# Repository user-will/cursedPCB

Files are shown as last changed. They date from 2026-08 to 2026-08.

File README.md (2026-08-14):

# Cursed PCB

Cursed PCB is a programmable light board with an ATtiny412 microcontroller, four individually addressable RGB LEDs, onboard USB-C power, and an onboard CH340 SerialUPDI programmer. Plug it into a computer, install the ATtiny board support in Arduino IDE, and upload your own light patterns.

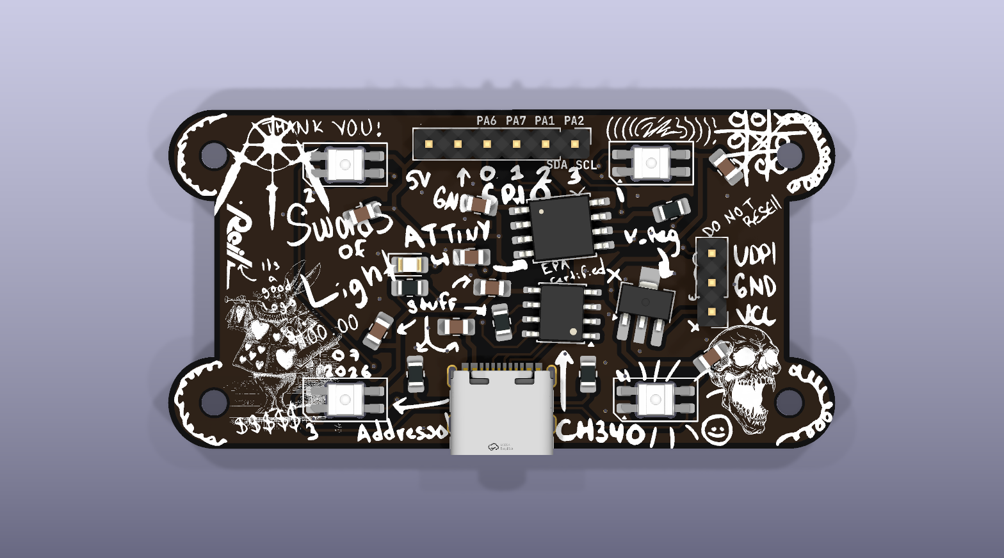
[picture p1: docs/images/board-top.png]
Top view of the Cursed PCB


> **Quick links:** [LED example](examples/LED_example/LED_example.ino) · [printable quick-start guide](docs/cursed-pcb-quick-start.pdf) · [nine-card Letter sheet](docs/cursed-pcb-card-sheet-letter-3x3.pdf) · [single 70 × 90 mm card](docs/cursed-pcb-setup-card-70x90mm.pdf) · [megaTinyCore documentation](https://github.com/SpenceKonde/megaTinyCore)

## Repository contents

- [`examples/LED_example/LED_example.ino`](examples/LED_example/LED_example.ino) — ready-to-upload LED animations and optional button support
- [`docs/cursed-pcb-quick-start.pdf`](docs/cursed-pcb-quick-start.pdf) — printable two-page quick-start guide
- [`docs/cursed-pcb-card-sheet-letter-3x3.pdf`](docs/cursed-pcb-card-sheet-letter-3x3.pdf) — nine 70 × 90 mm cards arranged 3 × 3 on US Letter paper
- [`docs/cursed-pcb-setup-card-70x90mm.pdf`](docs/cursed-pcb-setup-card-70x90mm.pdf) — one 70 × 90 mm setup card
- [`attiny412_addressable.kicad_sch`](attiny412_addressable.kicad_sch) — KiCad schematic
- [`attiny412_addressable.kicad_pcb`](attiny412_addressable.kicad_pcb) — KiCad PCB layout
- [`attiny412_addressable.kicad_pro`](attiny412_addressable.kicad_pro) — KiCad project settings

## Printing the setup cards

Use the [nine-card Letter sheet](docs/cursed-pcb-card-sheet-letter-3x3.pdf) to print nine cards on one single-sided sheet of US Letter paper or cardstock. Each finished card is 70 × 90 mm.

In the print dialog, select **Letter**, **Portrait**, **Actual size** or **100% scale**, and one-sided printing. Do not select “Fit to page.” Use the small corner marks to align your cuts.

## What you need

- The Cursed PCB
- A USB-C **data** cable (some charging-only cables cannot upload code)
- [Arduino IDE](https://www.arduino.cc/en/software)
- The `LED_example` sketch in this repository

No separate LED library download is required. The `tinyNeoPixel_Static` library used by the example is included with megaTinyCore.

## 1. Install ATtiny412 support

The ATtiny412 is not included in Arduino IDE by default. Install the **megaTinyCore** board package:

1. Open Arduino IDE.
2. Open **File → Preferences**. On macOS, open **Arduino IDE → Settings**.
3. Add this URL to **Additional Boards Manager URLs**:

   ```text
   http://drazzy.com/package_drazzy.com_index.json
   ```

   If another URL is already present, use the button beside the field and add this URL on a new line.

4. Open **Tools → Board → Boards Manager**.
5. Search for `megaTinyCore`.
6. Install the newest version of **megaTinyCore by Spence Konde**.

The package includes the compiler, upload utility, and `tinyNeoPixel` libraries needed by this board.

## 2. Connect and configure the board

Connect the board directly to the computer with a USB-C data cable. The power LED should turn on and a new serial port should appear in Arduino IDE.

Select these settings under **Tools**:

| Setting | Selection |
| --- | --- |
| Board | **megaTinyCore → ATtiny412/402/212/202** |
| Clock | **20 MHz internal** |
| BOD Voltage Level | **4.2V (20 MHz or less)** |
| millis()/micros() Timer | **Enabled (default timer)** |
| Programmer | **SerialUPDI - 230400 baud** |

Choose the board entry **without** “w/Optiboot.” This board programs the ATtiny412 directly over UPDI and does not need a bootloader.

The onboard CH340 connection is dedicated to UPDI programming. It is not connected to the ATtiny412's normal UART pins, so Arduino Serial Monitor will not display `Serial.print()` output through this USB-C connection. PA6/TX and PA7/RX remain available on the six-pin header for an external serial adapter.

## 3. Open and upload the example

1. Download or clone this repository.
2. Open [`examples/LED_example/LED_example.ino`](examples/LED_example/LED_example.ino) in Arduino IDE.
3. Compile with **Sketch → Verify/Compile**.
4. Upload with **Sketch → Upload Using Programmer**. The regular Upload button is not used for this UPDI setup.

After the upload finishes, the four LEDs run through red, green, blue, white, a rainbow sweep, and a moving white chase.

### Optional mode button

The example supports an optional normally-open pushbutton connected between exposed pins **0 (PA6)** and **2 (PA1)**. No external resistor is needed for this example: the sketch drives PA6 low and enables PA1's internal pull-up. Each press advances to the next animation.

If no button is connected, the example still works. It automatically shows the four solid colors and then continues with the rainbow sweep.

## Programming the lights

The four onboard LEDs are SK6812MINI-E addressable RGB LEDs connected as one chain. The first LED's data input is connected to **PA3**, which megaTinyCore calls Arduino pin **4**.

The important setup from the example is:

```cpp
#include <tinyNeoPixel_Static.h>

constexpr uint8_t LED_PIN = PIN_PA3;  // Arduino pin 4
constexpr uint8_t NUM_LEDS = 4;

byte pixelData[NUM_LEDS * 3];
tinyNeoPixel leds(NUM_LEDS, LED_PIN, NEO_GRB, pixelData);

void setup() {
  pinMode(LED_PIN, OUTPUT);
  leds.setBrightness(20);              // 0 to 255
  leds.setPixelColor(0, 255, 0, 0);   // first LED: red
  leds.show();
}
```

`tinyNeoPixel_Static` keeps the LED buffer in a fixed array, which is helpful on the ATtiny412's limited memory. Set colors with `setPixelColor()`, then call `show()` to send the updated buffer to the LEDs. The LEDs use `NEO_GRB` byte order.

Keep the brightness modest while experimenting. Four LEDs at full white use much more current and can be uncomfortably bright.

## Pinout

With the component side facing up and the USB-C connector at the bottom, the six-pin header reads left to right:

| Header label | Arduino pin | ATtiny412 pin | Common functions |
| --- | ---: | --- | --- |
| 5V | — | VDD | Regulated 5 V rail/output — **not an external power input** |
| GND | — | GND | Ground |
| 0 | 0 | PA6 | Digital I/O, DAC, UART TX |
| 1 | 1 | PA7 | Digital I/O, UART RX |
| 2 | 2 | PA1 | Digital I/O, I²C SDA |
| 3 | 3 | PA2 | Digital I/O, I²C SCL |

Arduino pin **4 / PA3** controls the onboard LEDs and is not on the six-pin header. **PA0 / UPDI** is reserved for programming.

The separate three-pin header is labeled **UPDI, GND, VCC** from top to bottom when the USB-C connector is at the bottom. For standalone external power, connect the supply's positive lead to **VCC** and its negative lead to **GND**. VCC feeds the onboard voltage regulator. **UPDI** is for advanced external programming; none of these pins are needed for normal USB-C programming.

## Power and handling

- For normal use, power and program the board through USB-C.
- For standalone external power, connect the supply to **VCC** and **GND** on the side three-pin header. **Do not power the board through the 5V pin.**
- VCC passes through an onboard **L78L05 linear regulator**. It produces a fixed 5 V rail and is rated for a maximum of **100 mA total output current**. The board itself and all four LEDs share that limit.
- The regulator needs approximately **7 V or more at VCC** to maintain a regulated 5 V output. Keep VCC at or below the **recommended 20 V maximum**. The regulator IC's 30 V rating is an absolute maximum, not a recommended operating voltage. Higher input voltage creates more heat and reduces the practical current available.
- Regulator heat is approximately `(VCC input − 5 V) × current`. Keep external supply voltage and LED brightness as low as practical. Four LEDs at high or full-white brightness can exceed the regulator's 100 mA rating.
- Never connect an external supply to VCC while USB-C is connected. The two power sources are not isolated.
- The exposed **5V** header pin is the regulator's output/board rail. It may be used only as a limited 5 V output when the board is properly powered; never feed an external supply into it.
- The board has exposed electronics. Prevent metal objects, conductive surfaces, and loose wires from shorting it.
- Disconnect power before changing wiring. Observe polarity when using external power.
- The LEDs can be very bright. Avoid staring directly at them at high brightness.

## Troubleshooting

### No serial port appears

- Try a known USB-C data cable and another USB port.
- Disconnect and reconnect the board while watching **Tools → Port**.
- If the computer does not recognize the onboard CH340 USB serial device, install the CH340 driver for your operating system.

### Upload fails or reports “UPDI initialization failed”

- Confirm **ATtiny412/402/212/202** (without Optiboot), **BOD Voltage Level → 4.2V**, and **SerialUPDI - 230400 baud** are selected.
- Use **Sketch → Upload Using Programmer**, not the regular Upload command.
- Close any serial monitor or other application using the board's port.
- Try **SerialUPDI - SLOW: 57600 baud** under **Tools → Programmer**.
- Unplug the board, reconnect it, reselect the port, and try again.

### The sketch uploads but the LEDs stay dark

- Confirm the sketch uses four pixels, `NEO_GRB`, and LED pin `PIN_PA3` or Arduino pin `4`.
- Make sure the LED data pin is configured as `OUTPUT` when using `tinyNeoPixel_Static`.
- Increase `setBrightness(20)` slightly while testing, but do not start at full brightness.

### The sketch is too large

The ATtiny412 has 4 KB of program flash and 256 bytes of SRAM. Prefer `tinyNeoPixel_Static`, avoid large strings and unnecessary libraries, and keep the pixel buffer at `4 × 3 = 12` bytes.

## Hardware summary

- ATtiny412, 4 KB flash / 256 bytes SRAM
- Four SK6812MINI-E addressable RGB LEDs
- USB-C connector with onboard CH340 SerialUPDI programming
- Side VCC external-power input through an L78L05 regulator: recommended 20 V maximum input, fixed 5 V output, 100 mA maximum total output
- Four exposed GPIO pins, including I²C SDA/SCL
- Approximately 58 mm × 29.5 mm
- Four 2.2 mm mounting holes

For deeper ATtiny and library information, see the official [megaTinyCore installation guide](https://github.com/SpenceKonde/megaTinyCore/blob/master/Installation.md), [megaTinyCore reference](https://github.com/SpenceKonde/megaTinyCore), and [tinyNeoPixel reference](https://github.com/SpenceKonde/megaTinyCore/blob/master/megaavr/extras/tinyNeoPixel.md).

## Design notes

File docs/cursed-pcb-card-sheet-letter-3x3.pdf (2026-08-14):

CURSED PCB | ATTINY412 / SETUP

# Set up Arduino

before uploading.

Use a USB-C data cable.

## 01 Install megaTinyCore

Arduino IDE → Preferences → Additional Boards Manager URLs:

http://drazzy.com/
package_drazzy.com_index.json
Boards Manager: install megaTinyCore by Spence Konde.
LED library included.

## 02 Choose these settings

BOARD | ATtiny412/402/212/202 without Optiboot
CLOCK | 20 MHz internal
BOD VOLTAGE | 4.2V (20 MHz or less)
PROGRAMMER | SerialUPDI – 230400 baud

## 03 Upload the example

Open LED_example.ino. Choose Sketch → Upload Using Programmer.

Power the board using the side VCC pin with up to 20V. Supplying raw voltage to the 5V pin may cause damage.

| FULL GUIDE + EXAMPLE CODE

### github.com/user-will/ cursedPCB

# STOP

CURSED PCB | ATTINY412 / SETUP

# Set up Arduino

before uploading.

Use a USB-C data cable.

## 01 Install megaTinyCore

Arduino IDE → Preferences → Additional Boards Manager URLs:

http://drazzy.com/
package_drazzy.com_index.json
Boards Manager: install megaTinyCore by Spence Konde.
LED library included.

## 02 Choose these settings

BOARD | ATtiny412/402/212/202 without Optiboot
CLOCK | 20 MHz internal
BOD VOLTAGE | 4.2V (20 MHz or less)
PROGRAMMER | SerialUPDI – 230400 baud

## 03 Upload the example

Open LED_example.ino. Choose Sketch → Upload Using Programmer.

Power the board using the side VCC pin with up to 20V. Supplying raw voltage to the 5V pin may cause damage.

| FULL GUIDE + EXAMPLE CODE

### github.com/user-will/ cursedPCB

# STOP

CURSED PCB | ATTINY412 / SETUP

# Set up Arduino

before uploading.

Use a USB-C data cable.

## 01 Install megaTinyCore

Arduino IDE → Preferences → Additional Boards Manager URLs:

http://drazzy.com/
package_drazzy.com_index.json
Boards Manager: install megaTinyCore by Spence Konde.
LED library included.

## 02 Choose these settings

BOARD | ATtiny412/402/212/202 without Optiboot
CLOCK | 20 MHz internal
BOD VOLTAGE | 4.2V (20 MHz or less)
PROGRAMMER | SerialUPDI – 230400 baud

## 03 Upload the example

Open LED_example.ino. Choose Sketch → Upload Using Programmer.

Power the board using the side VCC pin with up to 20V. Supplying raw voltage to the 5V pin may cause damage.

| FULL GUIDE + EXAMPLE CODE

### github.com/user-will/ cursedPCB

# STOP

CURSED PCB | ATTINY412 / SETUP

# Set up Arduino

before uploading.

Use a USB-C data cable.

## 01 Install megaTinyCore

Arduino IDE → Preferences → Additional Boards Manager URLs: http://drazzy.com/
package_drazzy.com_index.json
Boards Manager: install megaTinyCore by Spence Konde.
LED library included.

## 02 Choose these settings

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

## 03 Upload the example

Open LED_example.ino. Choose Sketch → Upload Using Programmer.

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

| FULL GUIDE + EXAMPLE CODE

### github.com/user-will/ cursedPCB

# STOP

CURSED PCB | ATTINY412 / SETUP

# Set up Arduino

before uploading.

Use a USB-C data cable.

## 01 Install megaTinyCore

Arduino IDE → Preferences → Additional Boards Manager URLs: http://drazzy.com/
package_drazzy.com_index.json
Boards Manager: install megaTinyCore by Spence Konde.
LED library included.

## 02 Choose these settings

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

## 03 Upload the example

Open LED_example.ino. Choose Sketch → Upload Using Programmer.

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

| FULL GUIDE + EXAMPLE CODE

### github.com/user-will/ cursedPCB

# STOP

CURSED PCB | ATTINY412 / SETUP

# Set up Arduino

before uploading.

Use a USB-C data cable.

## 01 Install megaTinyCore

Arduino IDE → Preferences → Additional Boards Manager URLs: http://drazzy.com/
package_drazzy.com_index.json
Boards Manager: install megaTinyCore by Spence Konde.
LED library included.

## 02 Choose these settings

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

## 03 Upload the example

Open LED_example.ino. Choose Sketch → Upload Using Programmer.

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

| FULL GUIDE + EXAMPLE CODE

### github.com/user-will/ cursedPCB

# STOP

CURSED PCB | ATTINY412 / SETUP

# Set up Arduino

before uploading.

Use a USB-C data cable.

## 01 Install megaTinyCore

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

## 02 Choose these settings

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

## 03 Upload the example

Open LED_example.ino. Choose Sketch → Upload Using Programmer.

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

| FULL GUIDE + EXAMPLE CODE

### github.com/user-will/ cursedPCB

# STOP

CURSED PCB | ATTINY412 / SETUP

# Set up Arduino

before uploading.

Use a USB-C data cable.

## 01 Install megaTinyCore

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

## 02 Choose these settings

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

## 03 Upload the example

Open LED_example.ino. Choose Sketch → Upload Using Programmer.

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

| FULL GUIDE + EXAMPLE CODE

### github.com/user-will/ cursedPCB

# STOP

CURSED PCB | ATTINY412 / SETUP

# Set up Arduino

before uploading.

Use a USB-C data cable.

## 01 Install megaTinyCore

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

## 02 Choose these settings

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

## 03 Upload the example

Open LED_example.ino. Choose Sketch → Upload Using Programmer.

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

| FULL GUIDE + EXAMPLE CODE

### github.com/user-will/ cursedPCB

# STOP

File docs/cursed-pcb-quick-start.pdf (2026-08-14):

PROGRAMMABLE ATTINY412 LIGHT BOARD

# Cursed PCB

Four addressable RGB LEDs, onboard USB-C power, and built-in SerialUPDI programming. This card gets the example running; the full guide and code live on GitHub.

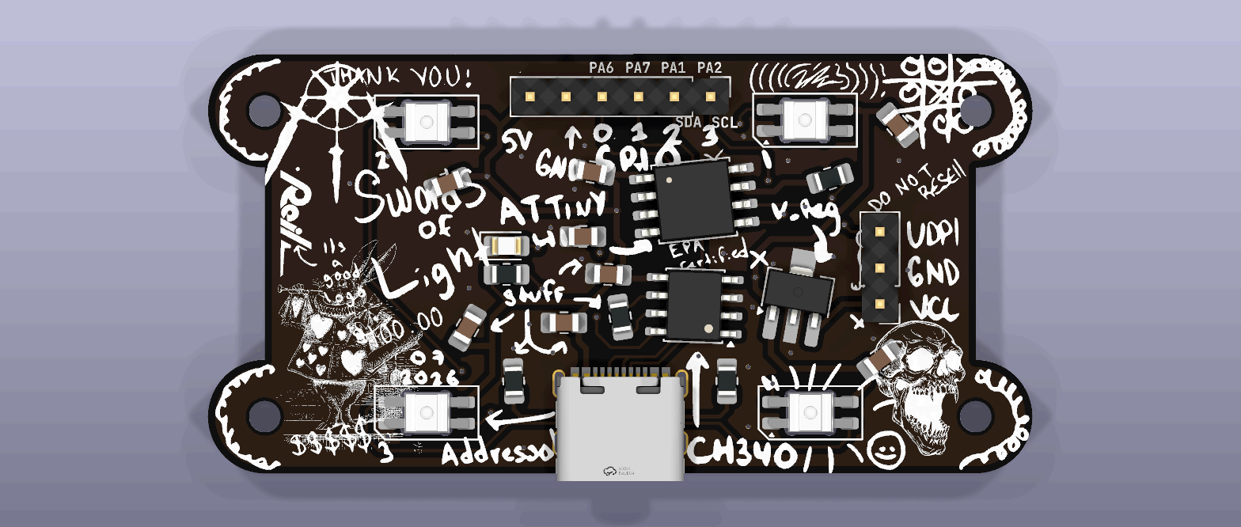
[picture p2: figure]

## Before you start

Use a USB-C data cable, not a charging-only cable.
Install Arduino IDE from arduino.cc/en/software.
No separate LED library is needed; megaTinyCore includes it.
For external power, use side-header VCC + GND—never the 5V pin. Recommended maximum: 20 V.

## Install the ATtiny board package

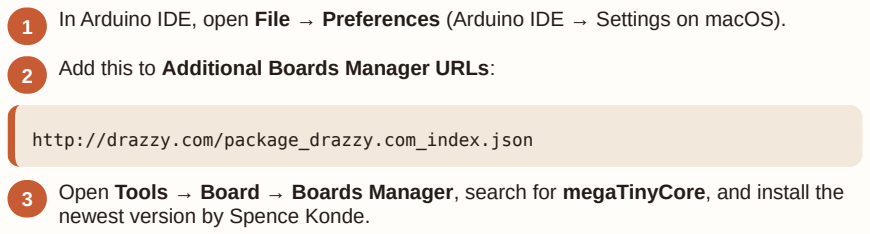
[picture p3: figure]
http://drazzy.com/package_drazzy.com_index.json; newest version by Spence Konde.

In Arduino IDE, open File → Preferences (Arduino IDE → Settings on macOS).

### 2 Add this to Additional Boards Manager URLs:

### 3 Open Tools → Board → Boards Manager, search for megaTinyCore, and install the

## Connect and choose these settings

Plug the board into the computer. The power LED should turn on and a new serial port should appear.

Tools menu | Choose
Board | ATtiny412/402/212/202 (without Optiboot)
Clock | 20 MHz internal
BOD Voltage Level | 4.2V (20 MHz or less)
Programmer | SerialUPDI - 230400 baud
Cursed PCB · Quick Start | 1 / 2

UPLOAD · PINS · TROUBLESHOOTING

# Make some light

## Get and upload the example

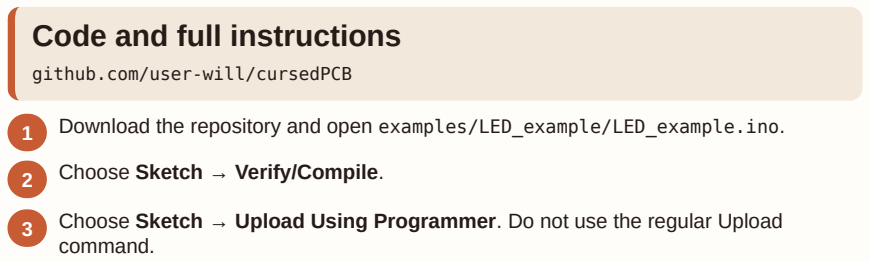
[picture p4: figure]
Code and full instructions; github.com/user-will/cursedPCB; 2 Choose Sketch → Verify/Compile.; command.

1 Download the repository and open examples/LED_example/LED_example.ino.

### 3 Choose Sketch → Upload Using Programmer. Do not use the regular Upload

The LEDs show red, green, blue, white, a rainbow sweep, and a moving white chase.

## Optional mode button

Connect a normally-open pushbutton between header pins 0 (PA6) and 2 (PA1). No external resistor is needed with the example sketch. Each press advances the animation. The LEDs still work without the button.

## Six-pin header

Component side up, USB-C at the bottom; read left to right:
Label | ATtiny | Use
5V | VDD | Regulated 5 V output; not a power input
GND | GND | Ground
0 | PA6 | Digital, DAC, TX
1 | PA7 | Digital, RX
2 | PA1 | Digital, I²C SDA
3 | PA2 | Digital, I²C SCL

The LEDs use PA3 / Arduino pin 4. PA0 is reserved for UPDI programming. The side three-pin header is UPDI, GND, VCC from top to bottom; VCC is the external-power input. The onboard USB connection programs UPDI; it is not a Serial Monitor connection.

## Troubleshooting

No port: try a known data cable or install a CH340 driver.
Upload error: recheck board, BOD voltage, and programmer; close Serial Monitor.
Still failing: select SerialUPDI - SLOW: 57600 baud.
Dark LEDs: use PIN_PA3, four pixels, and NEO_GRB.

## Power safely

| | Power the board using the side VCC pin with up to 20V. Supplying raw voltage to the 5V pin may cause damage.
Board size: about 58 × 29.5 mm | 2 / 2

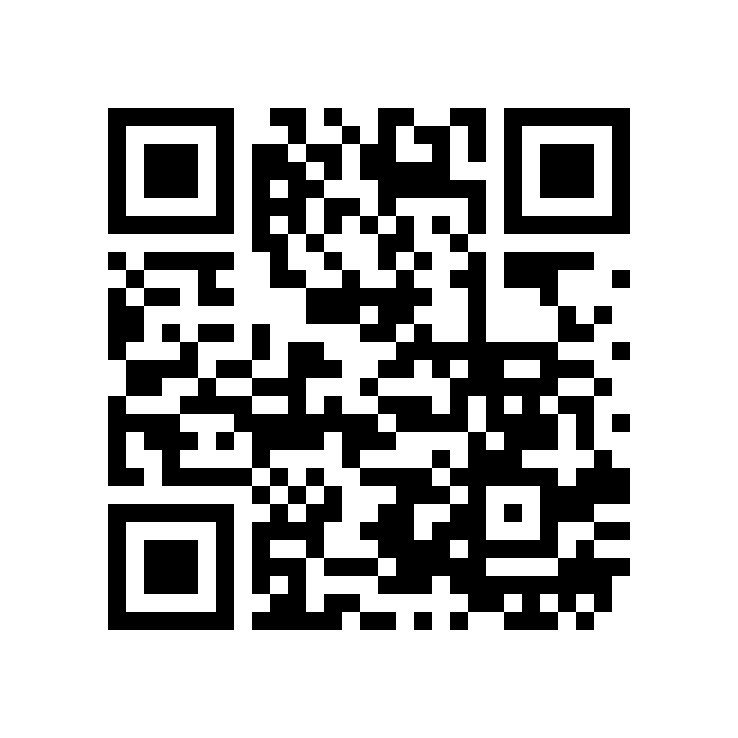
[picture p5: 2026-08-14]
docs/images/cursed-pcb-github-qr.png

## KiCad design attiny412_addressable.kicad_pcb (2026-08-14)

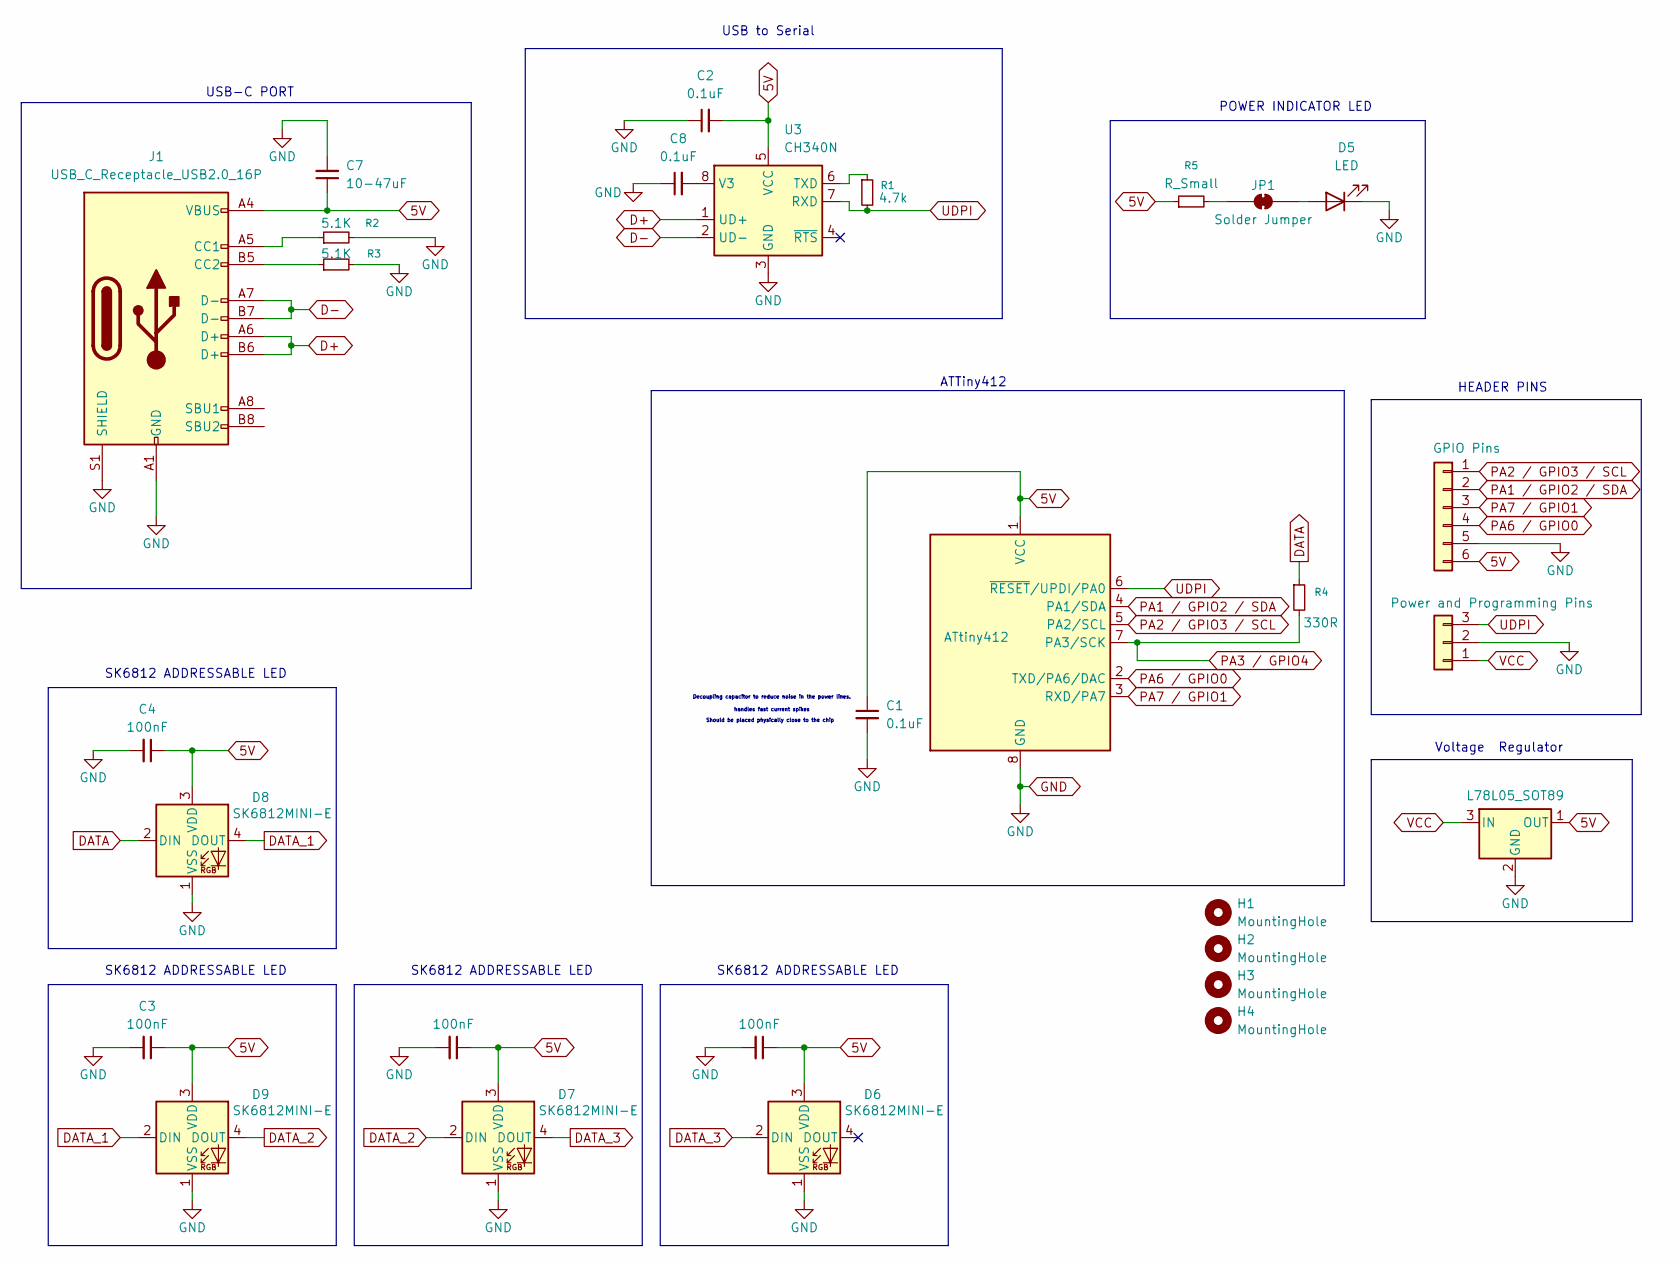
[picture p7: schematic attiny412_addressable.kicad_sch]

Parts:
C1: 0.1uF_0603_16V; C_0805_2012Metric_Pad1.18x1.45mm_HandSolder; Part Number 0603YC104KAT2A; JLCPCB ID C14663
C2, C8: 0.1uF; C_0805_2012Metric_Pad1.18x1.45mm_HandSolder
C3, C4, C5, C6: 100nF; C_0805_2012Metric_Pad1.18x1.45mm_HandSolder
C7: 10-47uF; C_0805_2012Metric_Pad1.18x1.45mm_HandSolder
D5: LED; LED_0805_2012Metric_Pad1.15x1.40mm_HandSolder
D6, D7, D8, D9: SK6812MINI-E; LED_SK6812MINI-E_3.2x2.8mm_P1.5mm_ReverseMount
H1, H2, H3, H4: MountingHole; MountingHole_2.2mm_M2
J1: USB_C_Receptacle_USB2.0_16P; USB_C_Receptacle_Palconn_UTC16-G
J2: GPIO Pins; PinHeader_1x06_P2.54mm_Vertical
J3: Power and Programming Pins; PinHeader_1x03_P2.54mm_Vertical
JP1: Solder Jumper; SolderJumper-2_P1.3mm_Bridged_RoundedPad1.0x1.5mm
R1: 4.7k; R_0805_2012Metric_Pad1.20x1.40mm_HandSolder
R2, R3: 5.1K; R_0805_2012Metric_Pad1.20x1.40mm_HandSolder
R4: 330R; R_0805_2012Metric_Pad1.20x1.40mm_HandSolder
R5: R_Small; R_0805_2012Metric_Pad1.20x1.40mm_HandSolder
U1: ATtiny412; SOIC-8_5.3x5.3mm_P1.27mm
U2: L78L05_SOT89; SOT-89-3_Handsoldering
U3: CH340N; JEITA_SOIC-8_3.9x4.9mm_P1.27mm

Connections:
5V: C1.1, C2.2, C3.1, C4.1, C5.1, C6.1, C7.1, D6.3 (VDD), D7.3 (VDD), D8.3 (VDD), D9.3 (VDD), J1.A4 (VBUS), J1.A9 (VBUS), J1.B4 (VBUS), J1.B9 (VBUS), J2.6, R5.1, U1.1 (VCC), U2.1 (OUT), U3.5 (VCC)
D+: J1.A6 (D+), J1.B6 (D+), U3.1 (UD+)
D-: J1.A7 (D-), J1.B7 (D-), U3.2 (UD-)
DATA: D8.2 (DIN), R4.1
DATA_1: D8.4 (DOUT), D9.2 (DIN)
DATA_2: D7.2 (DIN), D9.4 (DOUT)
DATA_3: D6.2 (DIN), D7.4 (DOUT)
GND: C1.2, C2.1, C3.2, C4.2, C5.2, C6.2, C7.2, C8.1, D5.1 (K), D6.1 (VSS), D7.1 (VSS), D8.1 (VSS), D9.1 (VSS), J1.A1 (GND), J1.A12 (GND), J1.B1 (GND), J1.B12 (GND), J1.S1 (SHIELD), J2.5, J3.2, R2.2, R3.2, U1.8 (GND), U2.2 (GND), U3.3 (GND)
unnamed: D5.2 (A), JP1.2 (B)
unnamed: J1.A5 (CC1), R2.1
unnamed: J1.B5 (CC2), R3.1
unnamed: JP1.1 (A), R5.2
unnamed: R1.1, U3.6 (TXD)
unnamed: C8.2, U3.8 (V3)
PA1 / GPIO2 / SDA: J2.2, U1.4 (PA1/SDA)
PA2 / GPIO3 / SCL: J2.1, U1.5 (PA2/SCL)
PA3 / GPIO4: R4.2, U1.7 (PA3/SCK)
PA6 / GPIO0: J2.4, U1.2 (TXD/PA6/DAC)
PA7 / GPIO1: J2.3, U1.3 (RXD/PA7)
UDPI: J3.3, R1.2, U1.6 (~RESET/UPDI/PA0), U3.7 (RXD)
VCC: J3.1, U2.3 (IN)

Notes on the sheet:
handles fast current spikes
SK6812 ADDRESSABLE LED
HEADER PINS
Should be placed physically close to the chip
USB to Serial
ATTiny412
POWER INDICATOR LED
USB-C PORT
Voltage Regulator
Decoupling capacitor to reduce noise in the power lines.

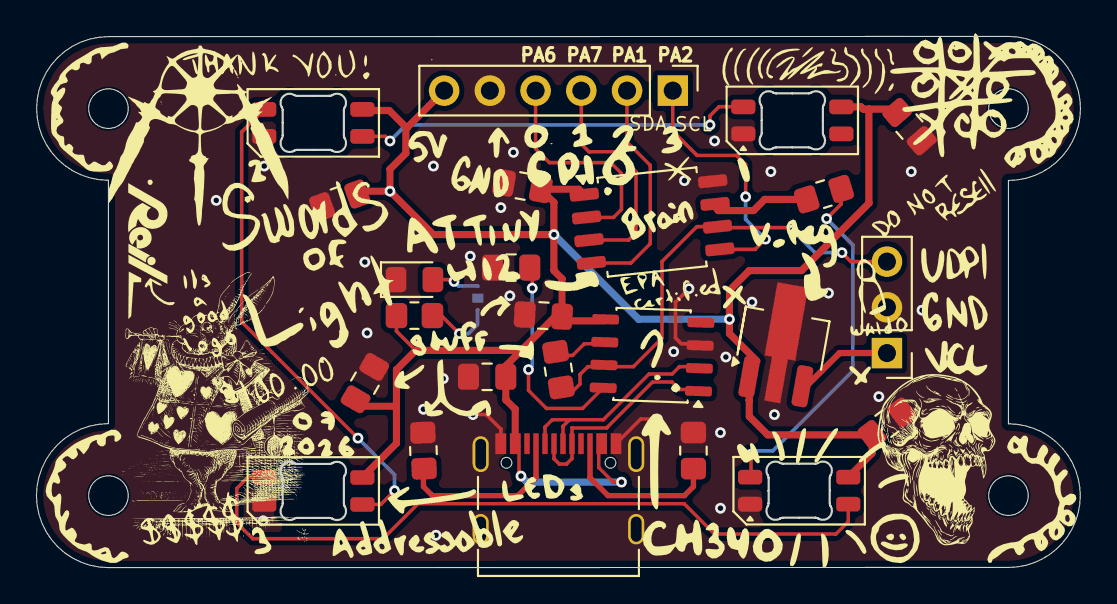
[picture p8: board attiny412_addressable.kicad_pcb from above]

Board: 2 copper layers, 58.0 x 29.5 mm, 29 parts (1 on the bottom side), 21 nets.

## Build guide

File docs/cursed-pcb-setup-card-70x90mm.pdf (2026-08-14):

CURSED PCB | ATTINY412 / SETUP

# Set up Arduino

before uploading.

Use a USB-C data cable.

## 01 Install megaTinyCore

Arduino IDE → Preferences → Additional Boards Manager URLs: http://drazzy.com/
package_drazzy.com_index.json
Boards Manager: install megaTinyCore by Spence Konde.
LED library included.

## 02 Choose these settings

BOARD | ATtiny412/402/212/202 without Optiboot
CLOCK | 20 MHz internal
BOD VOLTAGE | 4.2V (20 MHz or less)
PROGRAMMER | SerialUPDI – 230400 baud

## 03 Upload the example

Open LED_example.ino. Choose Sketch → Upload Using Programmer.

Power the board using the side VCC pin with up to 20V. Supplying raw voltage to the 5V pin may cause damage.

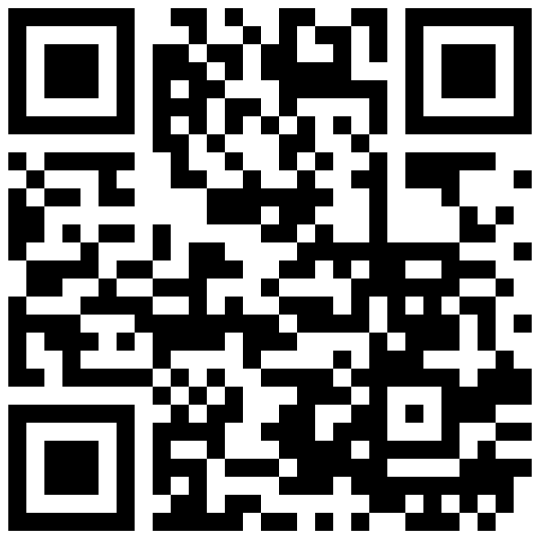
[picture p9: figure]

| FULL GUIDE + EXAMPLE CODE

### github.com/user-will/ cursedPCB

# STOP

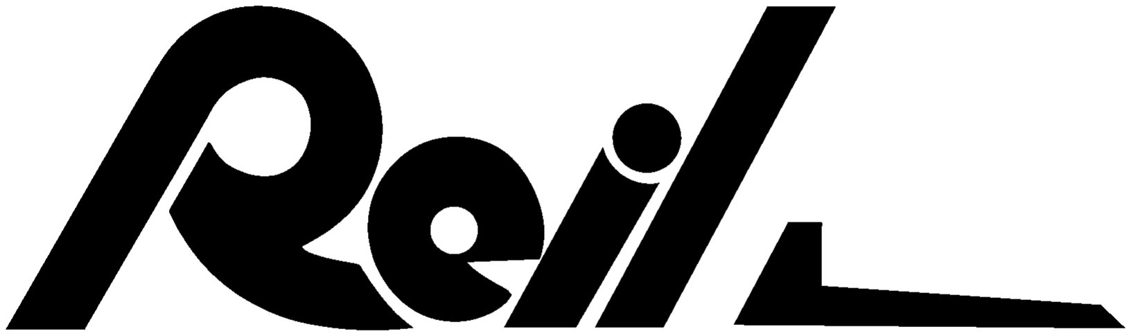
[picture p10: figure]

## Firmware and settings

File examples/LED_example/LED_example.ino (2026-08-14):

#include <tinyNeoPixel_Static.h>

// POWER: Use USB-C, or connect an external supply to VCC and GND on the
// side three-pin header. Do not use the 5V header pin as a power input.
// VCC feeds the onboard 5V regulator, which is limited to 100 mA total.

// The four onboard SK6812 LEDs form one chain on PA3 (Arduino pin 4).
constexpr uint8_t LED_PIN = PIN_PA3;
constexpr uint8_t NUM_LEDS = 4;

// Optional button: connect a normally-open pushbutton between exposed pins
// PA1 (Arduino pin 2) and PA6 (Arduino pin 0). PA6 acts as ground and PA1
// uses its internal pull-up, so no external resistor is required.
constexpr uint8_t BUTTON_PIN = PIN_PA1;
constexpr uint8_t BUTTON_GND_PIN = PIN_PA6;
constexpr unsigned long DEBOUNCE_MS = 30;

constexpr unsigned long PHASE_MS = 500;
constexpr uint16_t HUE_STEP = 32;
constexpr unsigned long ROTATION_INTERVAL_MS = 15;
constexpr unsigned long HUE_SWEEP_INTERVAL_MS = 4;

// tinyNeoPixel_Static uses this fixed buffer instead of dynamic allocation.
byte pixelData[NUM_LEDS * 3];
tinyNeoPixel leds(NUM_LEDS, LED_PIN, NEO_GRB, pixelData);

enum Phase : uint8_t {
  PHASE_RED,
  PHASE_GREEN,
  PHASE_BLUE,
  PHASE_WHITE,
  PHASE_SWEEP,
  PHASE_CHASE,
  PHASE_COUNT
};

uint8_t phase = PHASE_RED;
uint16_t hue = 0;
uint8_t chaseIndex = 0;

unsigned long lastRotation = 0;
unsigned long lastPhaseChange = 0;
unsigned long lastHueStep = 0;

bool lastButtonReading = HIGH;
bool buttonState = HIGH;
unsigned long lastDebounceTime = 0;

void setAll(byte red, byte green, byte blue) {
  for (uint8_t i = 0; i < NUM_LEDS; i++) {
    leds.setPixelColor(i, red, green, blue);
  }
  leds.show();
}

void applyPhase() {
  switch (phase) {
    case PHASE_RED:
      setAll(255, 0, 0);
      break;
    case PHASE_GREEN:
      setAll(0, 255, 0);
      break;
    case PHASE_BLUE:
      setAll(0, 0, 255);
      break;
    case PHASE_WHITE:
      setAll(255, 255, 255);
      break;
    case PHASE_SWEEP:
      for (uint8_t i = 0; i < NUM_LEDS; i++) {
        leds.setPixelColor(i, leds.ColorHSV(hue));
      }
      leds.show();
      break;
    case PHASE_CHASE:
      for (uint8_t i = 0; i < NUM_LEDS; i++) {
        leds.setPixelColor(i, i == chaseIndex ? 255 : 0,
                           i == chaseIndex ? 255 : 0,
                           i == chaseIndex ? 255 : 0);
      }
      leds.show();
      break;
    default:
      break;
  }
}

void nextPhase() {
  phase = (phase + 1) % PHASE_COUNT;
  hue = 0;
  chaseIndex = 0;
  lastPhaseChange = millis();
  applyPhase();
}

void checkButton() {
  const bool reading = digitalRead(BUTTON_PIN);

  if (reading != lastButtonReading) {
    lastDebounceTime = millis();
  }

  if (millis() - lastDebounceTime > DEBOUNCE_MS && reading != buttonState) {
    buttonState = reading;
    if (buttonState == LOW) {
      nextPhase();
    }
  }

  lastButtonReading = reading;
}

void setup() {
  pinMode(LED_PIN, OUTPUT);

  pinMode(BUTTON_GND_PIN, OUTPUT);
  digitalWrite(BUTTON_GND_PIN, LOW);
  pinMode(BUTTON_PIN, INPUT_PULLUP);

  // Bright enough to see clearly without starting at maximum LED current.
  leds.setBrightness(20);

  lastPhaseChange = millis();
  lastHueStep = millis();
  lastRotation = millis();
  applyPhase();
}

void loop() {
  const unsigned long now = millis();

  checkButton();

  switch (phase) {
    case PHASE_RED:
    case PHASE_GREEN:
    case PHASE_BLUE:
    case PHASE_WHITE:
      if (now - lastPhaseChange >= PHASE_MS) {
        nextPhase();
      }
      break;

    case PHASE_SWEEP:
      if (now - lastHueStep >= HUE_SWEEP_INTERVAL_MS) {
        hue += HUE_STEP;
        applyPhase();
        lastHueStep = now;
      }
      break;

    case PHASE_CHASE:
      if (now - lastRotation >= ROTATION_INTERVAL_MS) {
        chaseIndex = (chaseIndex + 1) % NUM_LEDS;
        applyPhase();
        lastRotation = now;
      }
      break;

    default:
      break;
  }
}

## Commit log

2026-08-14 Add Cursed PCB documentation and design files
    [attiny412_addressable.kicad_pcb, attiny412_addressable.kicad_sch]
2026-08-14 Correct external power instructions
    [LED_example.ino]
2026-08-14 Simplify quick-start power guidance
2026-08-14 Add QR code and nine-card print sheet
2026-08-14 Brand cards and refine print guidance
